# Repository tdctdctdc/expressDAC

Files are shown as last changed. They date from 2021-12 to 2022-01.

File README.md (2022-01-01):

# expressDAC

PCB ordered

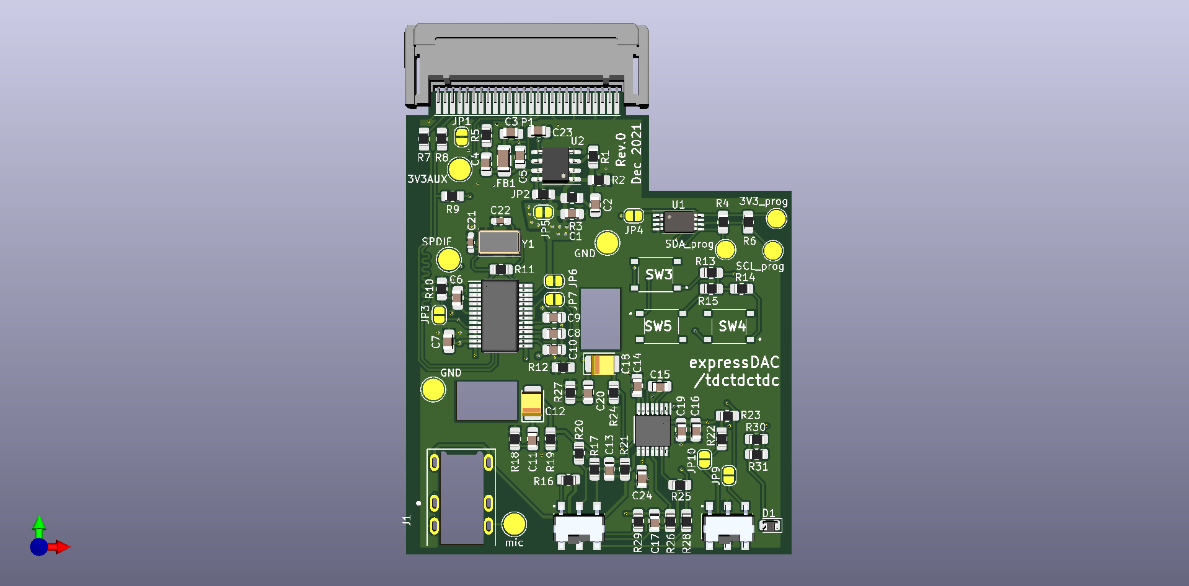
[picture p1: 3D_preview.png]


Proof of concept for a ExpressCard DAC

Using a TI part (PCM2704C) that does all the hard work (USB bridge + DAC) just to prove feasibility. It should be USB Audio class and need no driver whatsoever

Had to change the amplifier chip twice because of the shortage and it's pretty much the least interesting part. The LM4917 is very underwhelming compared to recent TI integrated, 3V3 headphone amplifier

The PCM2704C datasheet is very short (less than 50 pages for 4 variants of the chip !) and power supply rules are not clear. That's why there so many solder bridge. 

Also had to go with awkward footprints for the LDO and EEPROM because it's 2021 and everything is out of stock...

The main goal is to go noise free even with sensitive IEM.

Will be using salvaged expressCard connector since the only available commercial reference (100305702112lf) is on Arrow and I can't order it here.

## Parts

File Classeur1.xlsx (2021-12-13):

version | source | date | tool | number | name | tstamps | title | company | rev | date2 | source3 | number4 | value | ref | value5 | footprint | field | name6 | lib | part | description | names | tstamps7 | tstamp | datasheet | lib8 | part9 | description10 | docs | field11 | name12 | num | name13 | type | fp | alias | logical | uri | code | name14 | ref15 | pin
D |  |  |  |  |  |  |  |  |  |  |  |  |  |  | 0R | Resistor_SMD:R_0805_2012Metric_Pad1.20x1.40mm_HandSolder |  |  | Jumper | Jumper_2_Open | Jumper, 2-pole, open | / | / | 6129B10A | ~
D |  |  |  |  |  |  |  |  |  |  |  |  |  |  | 100k | Resistor_SMD:R_0805_2012Metric_Pad1.20x1.40mm_HandSolder |  |  | Device | R_Small_US | Resistor, small US symbol | / | / | 611EE0E7 | ~
D |  |  |  |  |  |  |  |  |  |  |  |  |  |  | 100k | Resistor_SMD:R_0805_2012Metric_Pad1.20x1.40mm_HandSolder |  |  | Device | R_Small_US | Resistor, small US symbol | / | / | 611E1D7C | ~
D |  |  |  |  |  |  |  |  |  |  |  |  |  |  | 100k | Resistor_SMD:R_0805_2012Metric_Pad1.20x1.40mm_HandSolder |  |  | Device | R_Small_US | Resistor, small US symbol | / | / | 616C3DC7 | ~
D |  |  |  |  |  |  |  |  |  |  |  |  |  |  | 100k | Resistor_SMD:R_0805_2012Metric_Pad1.20x1.40mm_HandSolder |  |  | Device | R_Small_US | Resistor, small US symbol | / | / | 616C469F | ~
D |  |  |  |  |  |  |  |  |  |  |  |  |  |  | 100k | Resistor_SMD:R_0805_2012Metric_Pad1.20x1.40mm_HandSolder |  |  | Device | R_Small_US | Resistor, small US symbol | / | / | 616C4A0D | ~
D |  |  |  |  |  |  |  |  |  |  |  |  |  |  | 100k | Resistor_SMD:R_0805_2012Metric_Pad1.20x1.40mm_HandSolder |  |  | Device | R_Small_US | Resistor, small US symbol | / | / | 618584DD | ~
D |  |  |  |  |  |  |  |  |  |  |  |  |  |  | 100k | Resistor_SMD:R_0805_2012Metric_Pad1.20x1.40mm_HandSolder |  |  | Device | R_Small_US | Resistor, small US symbol | / | / | 6189CDAD | ~
D |  |  |  |  |  |  |  |  |  |  |  |  |  |  | 100n | Capacitor_SMD:C_0805_2012Metric_Pad1.18x1.45mm_HandSolder |  |  | Device | C_Small | Unpolarized capacitor, small symbol | / | / | 6171208B | ~
D |  |  |  |  |  |  |  |  |  |  |  |  |  |  | 10k | Resistor_SMD:R_0805_2012Metric_Pad1.20x1.40mm_HandSolder |  |  | Device | R_US | Resistor, US symbol | / | / | 6115C9DD | ~
D |  |  |  |  |  |  |  |  |  |  |  |  |  |  |  | Capacitor_SMD:C_0805_2012Metric_Pad1.18x1.45mm_HandSolder |  |  | Device | C_Small | Unpolarized capacitor, small symbol | / | / | 6115BD5B | ~
D |  |  |  |  |  |  |  |  |  |  |  |  |  |  | 10u | Capacitor_SMD:C_0805_2012Metric_Pad1.18x1.45mm_HandSolder |  |  | Device | CP1_Small | Polarized capacitor, small US symbol | / | / | 612387CB | ~
D |  |  |  |  |  |  |  |  |  |  |  |  |  |  | 10u | Capacitor_Tantalum_SMD:CP_EIA-3528-21_Kemet-B_Pad1.50x2.35mm_HandSolder |  |  | Device | CP1_Small | Polarized capacitor, small US symbol | / | / | 611991A7 | ~
D |  |  |  |  |  |  |  |  |  |  |  |  |  |  | 10u | Capacitor_Tantalum_SMD:CP_EIA-3528-21_Kemet-B_Pad1.50x2.35mm_HandSolder |  |  | Device | CP1_Small | Polarized capacitor, small US symbol | / | / | 611C0A92 | ~
D |  |  |  |  |  |  |  |  |  |  |  |  |  |  | 10u | Capacitor_SMD:C_0805_2012Metric_Pad1.18x1.45mm_HandSolder |  |  | Device | CP1_Small | Polarized capacitor, small US symbol | / | / | 6134C5CA | ~
D |  |  |  |  |  |  |  |  |  |  |  |  |  |  | 15k | Resistor_SMD:R_0805_2012Metric_Pad1.20x1.40mm_HandSolder |  |  | Device | R_Small_US | Resistor, small US symbol | / | / | 61111F8E | ~
D |  |  |  |  |  |  |  |  |  |  |  |  |  |  | 18p | Capacitor_SMD:C_0603_1608Metric_Pad1.08x0.95mm_HandSolder |  |  | Device | C_Small | Unpolarized capacitor, small symbol | / | / | 6112DD15 | ~
D |  |  |  |  |  |  |  |  |  |  |  |  |  |  | 18p | Capacitor_SMD:C_0603_1608Metric_Pad1.08x0.95mm_HandSolder |  |  | Device | C_Small | Unpolarized capacitor, small symbol | / | / | 6112F506 | ~
D |  |  |  |  |  |  |  |  |  |  |  |  |  |  | 1k | Resistor_SMD:R_0805_2012Metric_Pad1.20x1.40mm_HandSolder |  |  | Device | R_Small_US | Resistor, small US symbol | / | / | 61117E01 | ~
D |  |  |  |  |  |  |  |  |  |  |  |  |  |  | 1k5 | Resistor_SMD:R_0805_2012Metric_Pad1.20x1.40mm_HandSolder |  |  | Device | R_Small_US | Resistor, small US symbol | / | / | 614A52DF | ~
D |  |  |  |  |  |  |  |  |  |  |  |  |  |  | 1M | Resistor_SMD:R_0805_2012Metric_Pad1.20x1.40mm_HandSolder |  |  | Device | R_Small_US | Resistor, small US symbol | / | / | 6113FC88 | ~
D |  |  |  |  |  |  |  |  |  |  |  |  |  |  | 1u | Capacitor_SMD:C_0805_2012Metric_Pad1.18x1.45mm_HandSolder |  |  | Device | C_Small | Unpolarized capacitor, small symbol | / | / | 611163AA | ~
D |  |  |  |  |  |  |  |  |  |  |  |  |  |  | 1u | Capacitor_SMD:C_0805_2012Metric_Pad1.18x1.45mm_HandSolder |  |  | Device | C_Small | Unpolarized capacitor, small symbol | / | / | 6116895D | ~
D |  |  |  |  |  |  |  |  |  |  |  |  |  |  | 1u | Capacitor_SMD:C_0805_2012Metric_Pad1.18x1.45mm_HandSolder |  |  | Device | C_Small | Unpolarized capacitor, small symbol | / | / | 6122887B | ~
D |  |  |  |  |  |  |  |  |  |  |  |  |  |  | 1u | Capacitor_SMD:C_0805_2012Metric_Pad1.18x1.45mm_HandSolder |  |  | Device | C_Small | Unpolarized capacitor, small symbol | / | / | 612515A7 | ~
D |  |  |  |  |  |  |  |  |  |  |  |  |  |  | 1u | Capacitor_SMD:C_0805_2012Metric_Pad1.18x1.45mm_HandSolder |  |  | Device | C_Small | Unpolarized capacitor, small symbol | / | / | 6125CF4C | ~
D |  |  |  |  |  |  |  |  |  |  |  |  |  |  | 1u | Capacitor_SMD:C_0805_2012Metric_Pad1.18x1.45mm_HandSolder |  |  | Device | C_Small | Unpolarized capacitor, small symbol | / | / | 61308E7B | ~
D |  |  |  |  |  |  |  |  |  |  |  |  |  |  | 2.2u | Capacitor_SMD:C_0805_2012Metric_Pad1.18x1.45mm_HandSolder |  |  | Device | C | Unpolarized capacitor | / | / | 611C6C12 | ~
D |  |  |  |  |  |  |  |  |  |  |  |  |  |  | 2.2u | Capacitor_SMD:C_0805_2012Metric_Pad1.18x1.45mm_HandSolder |  |  | Device | C | Unpolarized capacitor | / | / | 611D97B4 | ~
D |  |  |  |  |  |  |  |  |  |  |  |  |  |  | 20k | Resistor_SMD:R_0805_2012Metric_Pad1.20x1.40mm_HandSolder |  |  | Device | R_US | Resistor, US symbol | / | / | 61168B82 | ~
D |  |  |  |  |  |  |  |  |  |  |  |  |  |  | 20k | Resistor_SMD:R_0805_2012Metric_Pad1.20x1.40mm_HandSolder |  |  | Device | R_US | Resistor, US symbol | / | / | 615FAEEE | ~
D |  |  |  |  |  |  |  |  |  |  |  |  |  |  | 20k | Resistor_SMD:R_0805_2012Metric_Pad1.20x1.40mm_HandSolder |  |  | Device | R_US | Resistor, US symbol | / | / | 615FCD86 | ~
D |  |  |  |  |  |  |  |  |  |  |  |  |  |  | 220p | Capacitor_SMD:C_0805_2012Metric_Pad1.18x1.45mm_HandSolder |  |  | Device | C_Small | Unpolarized capacitor, small symbol | / | / | 611A2D30 | ~
D |  |  |  |  |  |  |  |  |  |  |  |  |  |  | 220p | Capacitor_SMD:C_0805_2012Metric_Pad1.18x1.45mm_HandSolder |  |  | Device | C_Small | Unpolarized capacitor, small symbol | / | / | 611C0A9C | ~
D |  |  |  |  |  |  |  |  |  |  |  |  |  |  | 22n | Capacitor_SMD:C_0805_2012Metric_Pad1.18x1.45mm_HandSolder |  |  | Device | C_Small | Unpolarized capacitor, small symbol | / | / | 613EB038 | ~
D |  |  |  |  |  |  |  |  |  |  |  |  |  |  | 22n | Capacitor_SMD:C_0805_2012Metric_Pad1.18x1.45mm_HandSolder |  |  | Device | C_Small | Unpolarized capacitor, small symbol | / | / | 613EBD72 | ~
D |  |  |  |  |  |  |  |  |  |  |  |  |  |  | 22R | Resistor_SMD:R_0805_2012Metric_Pad1.20x1.40mm_HandSolder |  |  | Device | R_Small_US | Resistor, small US symbol | / | / | 611486B3 | ~
D |  |  |  |  |  |  |  |  |  |  |  |  |  |  | 22R | Resistor_SMD:R_0805_2012Metric_Pad1.20x1.40mm_HandSolder |  |  | Device | R_Small_US | Resistor, small US symbol | / | / | 6114744C | ~
D |  |  |  |  |  |  |  |  |  |  |  |  |  |  | 22R | Resistor_SMD:R_0805_2012Metric_Pad1.20x1.40mm_HandSolder |  |  | Device | R_Small_US | Resistor, small US symbol | / | / | 613E8B5E | ~
D |  |  |  |  |  |  |  |  |  |  |  |  |  |  | 22R | Resistor_SMD:R_0805_2012Metric_Pad1.20x1.40mm_HandSolder |  |  | Device | R_Small_US | Resistor, small US symbol | / | / | 613E9E04 | ~
D |  |  |  |  |  |  |  |  |  |  |  |  |  |  | 24,3k | Resistor_SMD:R_0805_2012Metric_Pad1.20x1.40mm_HandSolder |  |  | Device | R_Small_US | Resistor, small US symbol | / | / | 6110FCD0 | ~
D |  |  |  |  |  |  |  |  |  |  |  |  |  |  | 24CW320T-I_OT | SamacSys_Parts:SOT95P280X145-5N | EEPROM 32 Kbit I2C Serial EEPROM with Software Write Protection, Industrial Temp | Description | 000_expresscard | 24CW320T-I_OT | EEPROM 32 Kbit I2C Serial EEPROM with Software Write Protection, Industrial Temp | / | / | 61501347 | https://componentsearchengine.com/Datasheets/1/24CW320T-I_OT.pdf
D |  |  |  |  |  |  |  |  |  |  |  |  |  |  | 24CW320T-I_OT | SamacSys_Parts:SOT95P280X145-5N | 1.45 | Height | 000_expresscard | 24CW320T-I_OT | EEPROM 32 Kbit I2C Serial EEPROM with Software Write Protection, Industrial Temp | / | / | 61501347 | https://componentsearchengine.com/Datasheets/1/24CW320T-I_OT.pdf
D |  |  |  |  |  |  |  |  |  |  |  |  |  |  | 24CW320T-I_OT | SamacSys_Parts:SOT95P280X145-5N | Microchip | Manufacturer_Name | 000_expresscard | 24CW320T-I_OT | EEPROM 32 Kbit I2C Serial EEPROM with Software Write Protection, Industrial Temp | / | / | 61501347 | https://componentsearchengine.com/Datasheets/1/24CW320T-I_OT.pdf
D |  |  |  |  |  |  |  |  |  |  |  |  |  |  | 24CW320T-I_OT | SamacSys_Parts:SOT95P280X145-5N | 24CW320T-I/OT | Manufacturer_Part_Number | 000_expresscard | 24CW320T-I_OT | EEPROM 32 Kbit I2C Serial EEPROM with Software Write Protection, Industrial Temp | / | / | 61501347 | https://componentsearchengine.com/Datasheets/1/24CW320T-I_OT.pdf
D |  |  |  |  |  |  |  |  |  |  |  |  |  |  | 24CW320T-I_OT | SamacSys_Parts:SOT95P280X145-5N | 579-24CW320T-I/OT | Mouser Part Number | 000_expresscard | 24CW320T-I_OT | EEPROM 32 Kbit I2C Serial EEPROM with Software Write Protection, Industrial Temp | / | / | 61501347 | https://componentsearchengine.com/Datasheets/1/24CW320T-I_OT.pdf
D |  |  |  |  |  |  |  |  |  |  |  |  |  |  | 24CW320T-I_OT | SamacSys_Parts:SOT95P280X145-5N | https://www.mouser.com/Search/Refine.aspx?Keyword=579-24CW320T-I%2FOT | Mouser Price/Stock | 000_expresscard | 24CW320T-I_OT | EEPROM 32 Kbit I2C Serial EEPROM with Software Write Protection, Industrial Temp | / | / | 61501347 | https://componentsearchengine.com/Datasheets/1/24CW320T-I_OT.pdf
D |  |  |  |  |  |  |  |  |  |  |  |  | R5 |  | 2R | Resistor_SMD:R_0805_2012Metric_Pad1.20x1.40mm_HandSolder |  |  | Device | R_Small_US | Resistor, small US symbol | / | / | 61309F95 | ~
D |  |  |  |  |  |  |  |  |  |  |  |  |  |  | 2u2 | Capacitor_SMD:C_0805_2012Metric_Pad1.18x1.45mm_HandSolder |  |  | Device | C_Small | Unpolarized capacitor, small symbol | / | / | 6111C309 | ~
D |  |  |  |  |  |  |  |  |  |  |  |  |  |  | 3V3_prog | TestPoint:TestPoint_Pad_D2.5mm |  |  | Connector | TestPoint | test point | / | / | 615730A0 | ~
D |  |  |  |  |  |  |  |  |  |  |  |  |  |  | 4.7u | Capacitor_SMD:C_0805_2012Metric_Pad1.18x1.45mm_HandSolder |  |  | Device | C | Unpolarized capacitor | / | / | 611EE218 | ~
D |  |  |  |  |  |  |  |  |  |  |  |  |  |  | 6k8 | Resistor_SMD:R_0805_2012Metric_Pad1.20x1.40mm_HandSolder |  |  | Device | R_US | Resistor, US symbol | / | / | 61236CEA | ~
D |  |  |  |  |  |  |  |  |  |  |  |  |  |  | 6k8 | Resistor_SMD:R_0805_2012Metric_Pad1.20x1.40mm_HandSolder |  |  | Device | R_US | Resistor, US symbol | / | / | 61293D7E | ~
D |  |  |  |  |  |  |  |  |  |  |  |  |  |  | ABM3C-12.000MHZ-D4Y-T | Crystal:Crystal_SMD_Abracon_ABM3C-4Pin_5.0x3.2mm |  |  | Device | Crystal | Two pin crystal | / | / | 61130E8C | ~
D |  |  |  |  |  |  |  |  |  |  |  |  |  |  | ADP7142AUJZ | Package_TO_SOT_SMD:TSOT-23-5 |  |  | Regulator_Linear | ADP7142AUJZ | 200mA, Low Noise, CMOS Low Dropout Regulator, Positive, Adjustable, TSOT-23-5 | / | / | 61105CFB | https://www.analog.com/media/en/technical-documentation/data-sheets/ADP7142.pdf
D |  |  |  |  |  |  |  |  |  |  |  |  |  |  | Express_Card | MYLIB:100305702112LF |  |  | 000_expresscard | Express_Card |  | / | / | 60F8C266
D |  |  |  |  |  |  |  |  |  |  |  |  |  |  | Ferrite_Bead_Small | Capacitor_SMD:C_1206_3216Metric_Pad1.33x1.80mm_HandSolder |  |  | Device | Ferrite_Bead_Small | Ferrite bead, small symbol | / | / | 611598B0 | ~
D |  |  |  |  |  |  |  |  |  |  |  |  |  |  | LM4917 | SamacSys_Parts:SOP65P640X120-14N | LM4917 Ground-Referenced, 95mW Stereo Headphone Amplifier | Description | 000_expresscard | LM4917 | LM4917 Ground-Referenced, 95mW Stereo Headphone Amplifier | / | / | 61834444 | http://www.ti.com/lit/gpn/lm4917
D |  |  |  |  |  |  |  |  |  |  |  |  |  |  | LM4917 | SamacSys_Parts:SOP65P640X120-14N | 1.2 | Height | 000_expresscard | LM4917 | LM4917 Ground-Referenced, 95mW Stereo Headphone Amplifier | / | / | 61834444 | http://www.ti.com/lit/gpn/lm4917
D |  |  |  |  |  |  |  |  |  |  |  |  |  |  | LM4917 | SamacSys_Parts:SOP65P640X120-14N | Texas Instruments | Manufacturer_Name | 000_expresscard | LM4917 | LM4917 Ground-Referenced, 95mW Stereo Headphone Amplifier | / | / | 61834444 | http://www.ti.com/lit/gpn/lm4917
D |  |  |  |  |  |  |  |  |  |  |  |  |  |  | LM4917 | SamacSys_Parts:SOP65P640X120-14N | LM4917MTX/NOPB | Manufacturer_Part_Number | 000_expresscard | LM4917 | LM4917 Ground-Referenced, 95mW Stereo Headphone Amplifier | / | / | 61834444 | http://www.ti.com/lit/gpn/lm4917
D |  |  |  |  |  |  |  |  |  |  |  |  |  |  | LM4917 | SamacSys_Parts:SOP65P640X120-14N | 926-LM4917MTX/NOPB | Mouser Part Number | 000_expresscard | LM4917 | LM4917 Ground-Referenced, 95mW Stereo Headphone Amplifier | / | / | 61834444 | http://www.ti.com/lit/gpn/lm4917
D |  |  |  |  |  |  |  |  |  |  |  |  |  |  | LM4917 | SamacSys_Parts:SOP65P640X120-14N | https://www.mouser.co.uk/ProductDetail/Texas-Instruments/LM4917MTX-NOPB?qs=QbsRYf82W3E34pt9CCcZSQ%3D%3D | Mouser Price/Stock | 000_expresscard | LM4917 | LM4917 Ground-Referenced, 95mW Stereo Headphone Amplifier | / | / | 61834444 | http://www.ti.com/lit/gpn/lm4917
D |  |  |  |  |  |  |  |  |  |  |  |  |  |  | mic | TestPoint:TestPoint_Pad_D3.0mm |  |  | Connector | TestPoint | test point | / | / | 6199E316 | ~
D |  |  |  |  |  |  |  |  |  |  |  |  |  | R17 | N/C | Resistor_SMD:R_0805_2012Metric_Pad1.20x1.40mm_HandSolder |  |  | Device | R_US | Resistor, US symbol | / | / | 612348EE | ~
D |  |  |  |  |  |  |  |  |  |  |  |  |  | R28 | N/C | Resistor_SMD:R_0805_2012Metric_Pad1.20x1.40mm_HandSolder |  |  | Device | R_US | Resistor, US symbol | / | / | 61293D78 | ~
D |  |  |  |  |  |  |  |  |  |  |  |  |  | R19 | N/C | Resistor_SMD:R_0805_2012Metric_Pad1.20x1.40mm_HandSolder |  |  | Device | R_Small_US | Resistor, small US symbol | / | / | 614B4043 | ~
D |  |  |  |  |  |  |  |  |  |  |  |  |  | R24 | N/C | Resistor_SMD:R_0805_2012Metric_Pad1.20x1.40mm_HandSolder |  |  | Device | R_Small_US | Resistor, small US symbol | / | / | 614B51AE | ~
D |  |  |  |  |  |  |  |  |  |  |  |  |  |  | PCM2704CDBR | SamacSys_Parts:SOP65P780X200-28N | 98dB SNR Stereo Full Speed DAC with line-out & S/PDIF output, Bus/Self-powered (Ext. ROM Interface) | Description | 000_expresscard | PCM2704CDBR | 98dB SNR Stereo Full Speed DAC with line-out & S/PDIF output, Bus/Self-powered (Ext. ROM Interface) | / | / | 616F0F6C | http://www.ti.com/lit/gpn/pcm2704c
D |  |  |  |  |  |  |  |  |  |  |  |  |  |  | PCM2704CDBR | SamacSys_Parts:SOP65P780X200-28N | 2 | Height | 000_expresscard | PCM2704CDBR | 98dB SNR Stereo Full Speed DAC with line-out & S/PDIF output, Bus/Self-powered (Ext. ROM Interface) | / | / | 616F0F6C | http://www.ti.com/lit/gpn/pcm2704c
D |  |  |  |  |  |  |  |  |  |  |  |  |  |  | PCM2704CDBR | SamacSys_Parts:SOP65P780X200-28N | Texas Instruments | Manufacturer_Name | 000_expresscard | PCM2704CDBR | 98dB SNR Stereo Full Speed DAC with line-out & S/PDIF output, Bus/Self-powered (Ext. ROM Interface) | / | / | 616F0F6C | http://www.ti.com/lit/gpn/pcm2704c
D |  |  |  |  |  |  |  |  |  |  |  |  |  |  | PCM2704CDBR | SamacSys_Parts:SOP65P780X200-28N | PCM2704CDBR | Manufacturer_Part_Number | 000_expresscard | PCM2704CDBR | 98dB SNR Stereo Full Speed DAC with line-out & S/PDIF output, Bus/Self-powered (Ext. ROM Interface) | / | / | 616F0F6C | http://www.ti.com/lit/gpn/pcm2704c
D |  |  |  |  |  |  |  |  |  |  |  |  |  |  | PCM2704CDBR | SamacSys_Parts:SOP65P780X200-28N | 595-PCM2704CDBR | Mouser Part Number | 000_expresscard | PCM2704CDBR | 98dB SNR Stereo Full Speed DAC with line-out & S/PDIF output, Bus/Self-powered (Ext. ROM Interface) | / | / | 616F0F6C | http://www.ti.com/lit/gpn/pcm2704c
D |  |  |  |  |  |  |  |  |  |  |  |  |  |  | PCM2704CDBR | SamacSys_Parts:SOP65P780X200-28N | https://www.mouser.co.uk/ProductDetail/Texas-Instruments/PCM2704CDBR/?qs=luhu8ESwuKyEcaL1a6bxNA%3D%3D | Mouser Price/Stock | 000_expresscard | PCM2704CDBR | 98dB SNR Stereo Full Speed DAC with line-out & S/PDIF output, Bus/Self-powered (Ext. ROM Interface) | / | / | 616F0F6C | http://www.ti.com/lit/gpn/pcm2704c
D |  |  |  |  |  |  |  |  |  |  |  |  |  |  | R_US | Resistor_SMD:R_0805_2012Metric_Pad1.20x1.40mm_HandSolder |  |  | Device | R_US | Resistor, US symbol | / | / | 611C0A70 | ~
D |  |  |  |  |  |  |  |  |  |  |  |  |  |  | R_US | Resistor_SMD:R_0805_2012Metric_Pad1.20x1.40mm_HandSolder |  |  | Device | R_US | Resistor, US symbol | / | / | 611C0A76 | ~
D |  |  |  |  |  |  |  |  |  |  |  |  |  |  | SCL_prog | TestPoint:TestPoint_Pad_D2.5mm |  |  | Connector | TestPoint | test point | / | / | 61643A62 | ~
D |  |  |  |  |  |  |  |  |  |  |  |  |  |  | SDA_prog | TestPoint:TestPoint_Pad_D2.5mm |  |  | Connector | TestPoint | test point | / | / | 61642B50 | ~
D |  |  |  |  |  |  |  |  |  |  |  |  |  |  | SJ2-35355A-SMT-TR | MYLIB:CUI_SJ2-35355A-SMT-TR | CUI | MF | 000_expresscard | SJ2-35355A-SMT-TR |  | / | / | 610A3ED8
D |  |  |  |  |  |  |  |  |  |  |  |  |  |  | SJ2-35355A-SMT-TR | MYLIB:CUI_SJ2-35355A-SMT-TR | SJ2-35355A-SMT-TR | MPN | 000_expresscard | SJ2-35355A-SMT-TR |  | / | / | 610A3ED8
D |  |  |  |  |  |  |  |  |  |  |  |  |  |  | SJ2-35355A-SMT-TR | MYLIB:CUI_SJ2-35355A-SMT-TR | Manufacturer recommendation | STANDARD | 000_expresscard | SJ2-35355A-SMT-TR |  | / | / | 610A3ED8
D |  |  |  |  |  |  |  |  |  |  |  |  |  |  | SolderJumper_2_Bridged | Jumper:SolderJumper-2_P1.3mm_Bridged_RoundedPad1.0x1.5mm |  |  | Jumper | SolderJumper_2_Bridged | Solder Jumper, 2-pole, closed/bridged | / | / | 6120BC43 | ~
D |  |  |  |  |  |  |  |  |  |  |  |  |  |  | SolderJumper_2_Bridged | Jumper:SolderJumper-2_P1.3mm_Bridged_RoundedPad1.0x1.5mm |  |  | Jumper | SolderJumper_2_Bridged | Solder Jumper, 2-pole, closed/bridged | / | / | 612B8AB4 | ~
D |  |  |  |  |  |  |  |  |  |  |  |  |  |  | SolderJumper_2_Bridged | Jumper:SolderJumper-2_P1.3mm_Bridged_RoundedPad1.0x1.5mm |  |  | Jumper | SolderJumper_2_Bridged | Solder Jumper, 2-pole, closed/bridged | / | / | 61377CE6 | ~
D |  |  |  |  |  |  |  |  |  |  |  |  |  |  | SolderJumper_2_Open | Jumper:SolderJumper-2_P1.3mm_Open_RoundedPad1.0x1.5mm |  |  | Jumper | SolderJumper_2_Open | Solder Jumper, 2-pole, open | / | / | 611ECFCB | ~
D |  |  |  |  |  |  |  |  |  |  |  |  |  |  | SolderJumper_2_Open | Jumper:SolderJumper-2_P1.3mm_Open_RoundedPad1.0x1.5mm |  |  | Jumper | SolderJumper_2_Open | Solder Jumper, 2-pole, open | / | / | 6128F622 | ~
D |  |  |  |  |  |  |  |  |  |  |  |  |  |  | SolderJumper_2_Open | Jumper:SolderJumper-2_P1.3mm_Open_RoundedPad1.0x1.5mm |  |  | Jumper | SolderJumper_2_Open | Solder Jumper, 2-pole, open | / | / | 61410325 | ~
D |  |  |  |  |  |  |  |  |  |  |  |  |  |  | SolderJumper_2_Open | Jumper:SolderJumper-2_P1.3mm_Open_RoundedPad1.0x1.5mm |  |  | Jumper | SolderJumper_2_Open | Solder Jumper, 2-pole, open | / | / | 61412C7E | ~
D |  |  |  |  |  |  |  |  |  |  |  |  |  |  | SolderJumper_2_Open | Jumper:SolderJumper-2_P1.3mm_Open_RoundedPad1.0x1.5mm |  |  | Jumper | SolderJumper_2_Open | Solder Jumper, 2-pole, open | / | / | 6154326C | ~
D |  |  |  |  |  |  |  |  |  |  |  |  |  |  | SolderJumper_2_Open | Jumper:SolderJumper-2_P1.3mm_Open_RoundedPad1.0x1.5mm |  |  | Jumper | SolderJumper_2_Open | Solder Jumper, 2-pole, open | / | / | 61857940 | ~
D |  |  |  |  |  |  |  |  |  |  |  |  |  |  | SolderJumper_2_Open | Jumper:SolderJumper-2_P1.3mm_Open_RoundedPad1.0x1.5mm |  |  | Jumper | SolderJumper_2_Open | Solder Jumper, 2-pole, open | / | / | 61857D33 | ~
D |  |  |  |  |  |  |  |  |  |  |  |  |  |  | SPDIF | TestPoint:TestPoint_Pad_D3.0mm |  |  | Connector | TestPoint | test point | / | / | 61A00691 | ~
D |  |  |  |  |  |  |  |  |  |  |  |  |  |  | SW_DPDT_x2 | SamacSys_Parts:PTS526SM08SMTR2LFS |  |  | Switch | SW_Push | Push button switch, generic, two pins | / | / | 61177A72 | ~
D |  |  |  |  |  |  |  |  |  |  |  |  |  |  | SW_DPDT_x2 | SamacSys_Parts:PTS526SM08SMTR2LFS |  |  | Switch | SW_Push | Push button switch, generic, two pins | / | / | 611C3B86 | ~
D |  |  |  |  |  |  |  |  |  |  |  |  |  |  | SW_DPDT_x2 | SamacSys_Parts:PTS526SM08SMTR2LFS |  |  | Switch | SW_Push | Push button switch, generic, two pins | / | / | 611C44CD | ~
D |  |  |  |  |  |  |  |  |  |  |  |  |  |  | SW_DPDT_x2 | SamacSys_Parts:AYZ0202AGRLC |  |  | Switch | SW_DPDT_x2 | Switch, dual pole double throw, separate symbols | / | / | 612225A5
D |  |  |  |  |  |  |  |  |  |  |  |  |  |  | SW_DPDT_x2 | SamacSys_Parts:AYZ0202AGRLC |  |  | Switch | SW_DPDT_x2 | Switch, dual pole double throw, separate symbols | / | / | 613BDD1F
D | C:\Users\Thomas\CAD\expressUSB\expressUSB\expressDAC.sch | 15/11/2021 23:08:59 | Eeschema (5.1.7)-1 | 1 | / | / |  |  |  |  | expressDAC.sch | 1
D | C:\Users\Thomas\CAD\expressUSB\expressUSB\expressDAC.sch | 15/11/2021 23:08:59 | Eeschema (5.1.7)-1 | 1 | / | / |  |  |  |  | expressDAC.sch | 2
D | C:\Users\Thomas\CAD\expressUSB\expressUSB\expressDAC.sch | 15/11/2021 23:08:59 | Eeschema (5.1.7)-1 | 1 | / | / |  |  |  |  | expressDAC.sch | 3
D | C:\Users\Thomas\CAD\expressUSB\expressUSB\expressDAC.sch | 15/11/2021 23:08:59 | Eeschema (5.1.7)-1 | 1 | / | / |  |  |  |  | expressDAC.sch | 4
D |  |  |  |  |  |  |  |  |  |  |  |  |  |  |  |  |  |  |  |  |  |  |  |  |  | 000_expresscard | 24CW320T-I_OT | EEPROM 32 Kbit I2C Serial EEPROM with Software Write Protection, Industrial Temp | https://componentsearchengine.com/Datasheets/1/24CW320T-I_OT.pdf | U | Reference
D |  |  |  |  |  |  |  |  |  |  |  |  |  |  |  |  |  |  |  |  |  |  |  |  |  | 000_expresscard | 24CW320T-I_OT | EEPROM 32 Kbit I2C Serial EEPROM with Software Write Protection, Industrial Temp | https://componentsearchengine.com/Datasheets/1/24CW320T-I_OT.pdf | 24CW320T-I_OT | Value
D |  |  |  |  |  |  |  |  |  |  |  |  |  |  |  |  |  |  |  |  |  |  |  |  |  | 000_expresscard | 24CW320T-I_OT | EEPROM 32 Kbit I2C Serial EEPROM with Software Write Protection, Industrial Temp | https://componentsearchengine.com/Datasheets/1/24CW320T-I_OT.pdf | SOT95P280X145-5N | Footprint
D |  |  |  |  |  |  |  |  |  |  |  |  |  |  |  |  |  |  |  |  |  |  |  |  |  | 000_expresscard | 24CW320T-I_OT | EEPROM 32 Kbit I2C Serial EEPROM with Software Write Protection, Industrial Temp | https://componentsearchengine.com/Datasheets/1/24CW320T-I_OT.pdf | https://componentsearchengine.com/Datasheets/1/24CW320T-I_OT.pdf | Datasheet
D |  |  |  |  |  |  |  |  |  |  |  |  |  |  |  |  |  |  |  |  |  |  |  |  |  | 000_expresscard | 24CW320T-I_OT | EEPROM 32 Kbit I2C Serial EEPROM with Software Write Protection, Industrial Temp | https://componentsearchengine.com/Datasheets/1/24CW320T-I_OT.pdf | EEPROM 32 Kbit I2C Serial EEPROM with Software Write Protection, Industrial Temp | Description
D |  |  |  |  |  |  |  |  |  |  |  |  |  |  |  |  |  |  |  |  |  |  |  |  |  | 000_expresscard | 24CW320T-I_OT | EEPROM 32 Kbit I2C Serial EEPROM with Software Write Protection, Industrial Temp | https://componentsearchengine.com/Datasheets/1/24CW320T-I_OT.pdf | 1.45 | Height
D |  |  |  |  |  |  |  |  |  |  |  |  |  |  |  |  |  |  |  |  |  |  |  |  |  | 000_expresscard | 24CW320T-I_OT | EEPROM 32 Kbit I2C Serial EEPROM with Software Write Protection, Industrial Temp | https://componentsearchengine.com/Datasheets/1/24CW320T-I_OT.pdf | 579-24CW320T-I/OT | Mouser Part Number
D |  |  |  |  |  |  |  |  |  |  |  |  |  |  |  |  |  |  |  |  |  |  |  |  |  | 000_expresscard | 24CW320T-I_OT | EEPROM 32 Kbit I2C Serial EEPROM with Software Write Protection, Industrial Temp | https://componentsearchengine.com/Datasheets/1/24CW320T-I_OT.pdf | https://www.mouser.com/Search/Refine.aspx?Keyword=579-24CW320T-I%2FOT | Mouser Price/Stock
D |  |  |  |  |  |  |  |  |  |  |  |  |  |  |  |  |  |  |  |  |  |  |  |  |  | 000_expresscard | 24CW320T-I_OT | EEPROM 32 Kbit I2C Serial EEPROM with Software Write Protection, Industrial Temp | https://componentsearchengine.com/Datasheets/1/24CW320T-I_OT.pdf | Microchip | Manufacturer_Name
D |  |  |  |  |  |  |  |  |  |  |  |  |  |  |  |  |  |  |  |  |  |  |  |  |  | 000_expresscard | 24CW320T-I_OT | EEPROM 32 Kbit I2C Serial EEPROM with Software Write Protection, Industrial Temp | https://componentsearchengine.com/Datasheets/1/24CW320T-I_OT.pdf | 24CW320T-I/OT | Manufacturer_Part_Number
D |  |  |  |  |  |  |  |  |  |  |  |  |  |  |  |  |  |  |  |  |  |  |  |  |  | 000_expresscard | 24CW320T-I_OT | EEPROM 32 Kbit I2C Serial EEPROM with Software Write Protection, Industrial Temp | https://componentsearchengine.com/Datasheets/1/24CW320T-I_OT.pdf |  |  | 1 | SCL | passive
D |  |  |  |  |  |  |  |  |  |  |  |  |  |  |  |  |  |  |  |  |  |  |  |  |  | 000_expresscard | 24CW320T-I_OT | EEPROM 32 Kbit I2C Serial EEPROM with Software Write Protection, Industrial Temp | https://componentsearchengine.com/Datasheets/1/24CW320T-I_OT.pdf |  |  | 2 | VSS | passive
D |  |  |  |  |  |  |  |  |  |  |  |  |  |  |  |  |  |  |  |  |  |  |  |  |  | 000_expresscard | 24CW320T-I_OT | EEPROM 32 Kbit I2C Serial EEPROM with Software Write Protection, Industrial Temp | https://componentsearchengine.com/Datasheets/1/24CW320T-I_OT.pdf |  |  | 3 | SDA | passive
D |  |  |  |  |  |  |  |  |  |  |  |  |  |  |  |  |  |  |  |  |  |  |  |  |  | 000_expresscard | 24CW320T-I_OT | EEPROM 32 Kbit I2C Serial EEPROM with Software Write Protection, Industrial Temp | https://componentsearchengine.com/Datasheets/1/24CW320T-I_OT.pdf |  |  | 4 | VCC | passive
D |  |  |  |  |  |  |  |  |  |  |  |  |  |  |  |  |  |  |  |  |  |  |  |  |  | 000_expresscard | 24CW320T-I_OT | EEPROM 32 Kbit I2C Serial EEPROM with Software Write Protection, Industrial Temp | https://componentsearchengine.com/Datasheets/1/24CW320T-I_OT.pdf |  |  | 5 | NC | NotConnected
D |  |  |  |  |  |  |  |  |  |  |  |  |  |  |  |  |  |  |  |  |  |  |  |  |  | 000_expresscard | Express_Card |  |  | P | Reference
D |  |  |  |  |  |  |  |  |  |  |  |  |  |  |  |  |  |  |  |  |  |  |  |  |  | 000_expresscard | Express_Card |  |  | Express_Card | Value
D |  |  |  |  |  |  |  |  |  |  |  |  |  |  |  |  |  |  |  |  |  |  |  |  |  | 000_expresscard | Express_Card |  |  |  |  | 1 | GND | unspc
D |  |  |  |  |  |  |  |  |  |  |  |  |  |  |  |  |  |  |  |  |  |  |  |  |  | 000_expresscard | Express_Card |  |  |  |  | 2 | USB_D- | unspc
D |  |  |  |  |  |  |  |  |  |  |  |  |  |  |  |  |  |  |  |  |  |  |  |  |  | 000_expresscard | Express_Card |  |  |  |  | 3 | USB_D+ | unspc
D |  |  |  |  |  |  |  |  |  |  |  |  |  |  |  |  |  |  |  |  |  |  |  |  |  | 000_expresscard | Express_Card |  |  |  |  | 4 | CP_USB | unspc
D |  |  |  |  |  |  |  |  |  |  |  |  |  |  |  |  |  |  |  |  |  |  |  |  |  | 000_expresscard | Express_Card |  |  |  |  | 5 | RSVD0 | unspc
D |  |  |  |  |  |  |  |  |  |  |  |  |  |  |  |  |  |  |  |  |  |  |  |  |  | 000_expresscard | Express_Card |  |  |  |  | 6 | RSVD0 | unspc
D |  |  |  |  |  |  |  |  |  |  |  |  |  |  |  |  |  |  |  |  |  |  |  |  |  | 000_expresscard | Express_Card |  |  |  |  | 7 | SMB_CLK | unspc
D |  |  |  |  |  |  |  |  |  |  |  |  |  |  |  |  |  |  |  |  |  |  |  |  |  | 000_expresscard | Express_Card |  |  |  |  | 8 | SMB_DATA | unspc
D |  |  |  |  |  |  |  |  |  |  |  |  |  |  |  |  |  |  |  |  |  |  |  |  |  | 000_expresscard | Express_Card |  |  |  |  | 9 | 1.5V | unspc
D |  |  |  |  |  |  |  |  |  |  |  |  |  |  |  |  |  |  |  |  |  |  |  |  |  | 000_expresscard | Express_Card |  |  |  |  | 10 | 1.5V | unspc
D |  |  |  |  |  |  |  |  |  |  |  |  |  |  |  |  |  |  |  |  |  |  |  |  |  | 000_expresscard | Express_Card |  |  |  |  | 11 | WAKE# | unspc
D |  |  |  |  |  |  |  |  |  |  |  |  |  |  |  |  |  |  |  |  |  |  |  |  |  | 000_expresscard | Express_Card |  |  |  |  | 12 | +3.3VAUX# | unspc
D |  |  |  |  |  |  |  |  |  |  |  |  |  |  |  |  |  |  |  |  |  |  |  |  |  | 000_expresscard | Express_Card |  |  |  |  | 13 | PERST# | unspc
D |  |  |  |  |  |  |  |  |  |  |  |  |  |  |  |  |  |  |  |  |  |  |  |  |  | 000_expresscard | Express_Card |  |  |  |  | 14 | +3.3V | unspc
D |  |  |  |  |  |  |  |  |  |  |  |  |  |  |  |  |  |  |  |  |  |  |  |  |  | 000_expresscard | Express_Card |  |  |  |  | 15 | +3.3V | unspc
D |  |  |  |  |  |  |  |  |  |  |  |  |  |  |  |  |  |  |  |  |  |  |  |  |  | 000_expresscard | Express_Card |  |  |  |  | 16 | CLKREG# | unspc
D |  |  |  |  |  |  |  |  |  |  |  |  |  |  |  |  |  |  |  |  |  |  |  |  |  | 000_expresscard | Express_Card |  |  |  |  | 17 | GND | unspc
D |  |  |  |  |  |  |  |  |  |  |  |  |  |  |  |  |  |  |  |  |  |  |  |  |  | 000_expresscard | Express_Card |  |  |  |  | 18 | REFCLK- | unspc
D |  |  |  |  |  |  |  |  |  |  |  |  |  |  |  |  |  |  |  |  |  |  |  |  |  | 000_expresscard | Express_Card |  |  |  |  | 19 | REFCLK+ | unspc
D |  |  |  |  |  |  |  |  |  |  |  |  |  |  |  |  |  |  |  |  |  |  |  |  |  | 000_expresscard | Express_Card |  |  |  |  | 20 | GND | unspc
D |  |  |  |  |  |  |  |  |  |  |  |  |  |  |  |  |  |  |  |  |  |  |  |  |  | 000_expresscard | Express_Card |  |  |  |  | 21 | PER0- | unspc
D |  |  |  |  |  |  |  |  |  |  |  |  |  |  |  |  |  |  |  |  |  |  |  |  |  | 000_expresscard | Express_Card |  |  |  |  | 22 | PER0+ | unspc
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

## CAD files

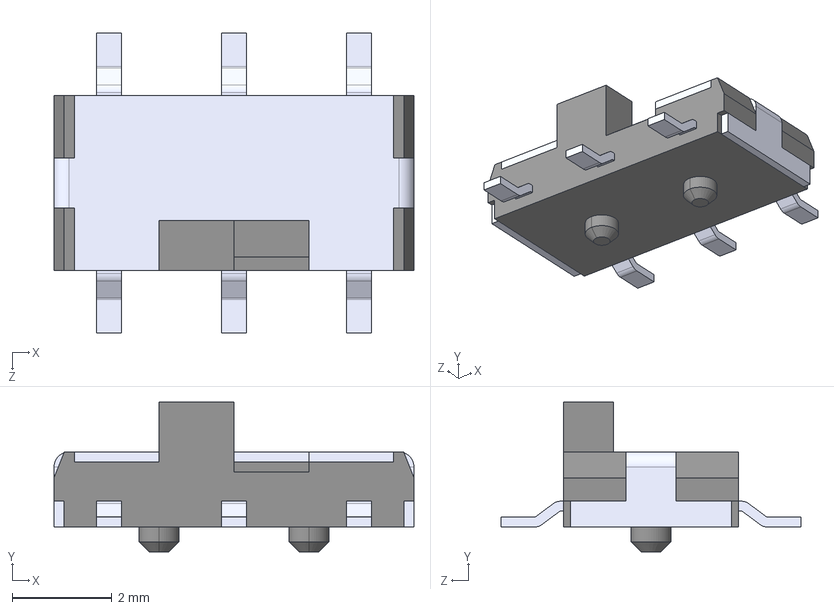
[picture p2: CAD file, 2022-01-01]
3D/AYZ0202AGRLC--3DModel-STEP-56544.STEP
7.20 x 3.00 x 6.00 mm

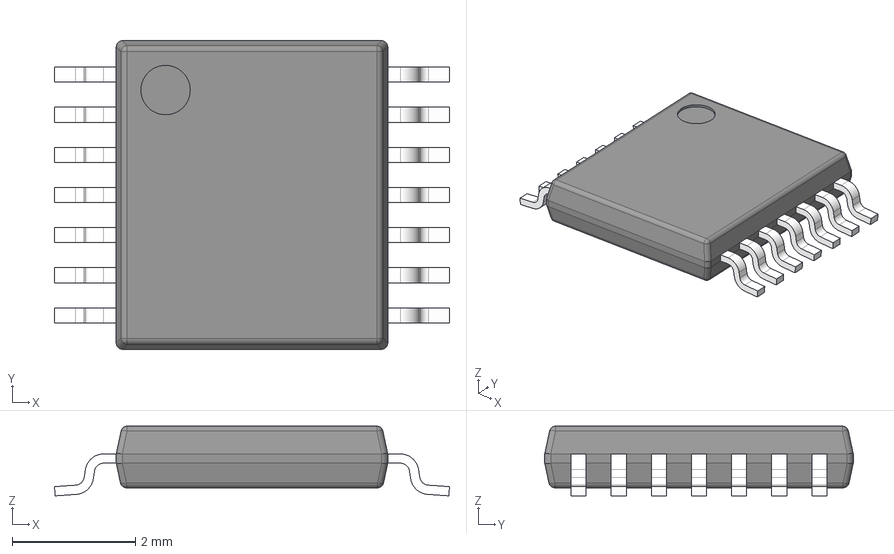
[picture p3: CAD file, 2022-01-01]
3D/LM4917MTX_NOPB.stp
6.40 x 5.00 x 1.13 mm
BODY-TSSOP
LEAD-TSSOP x 14
PIN1

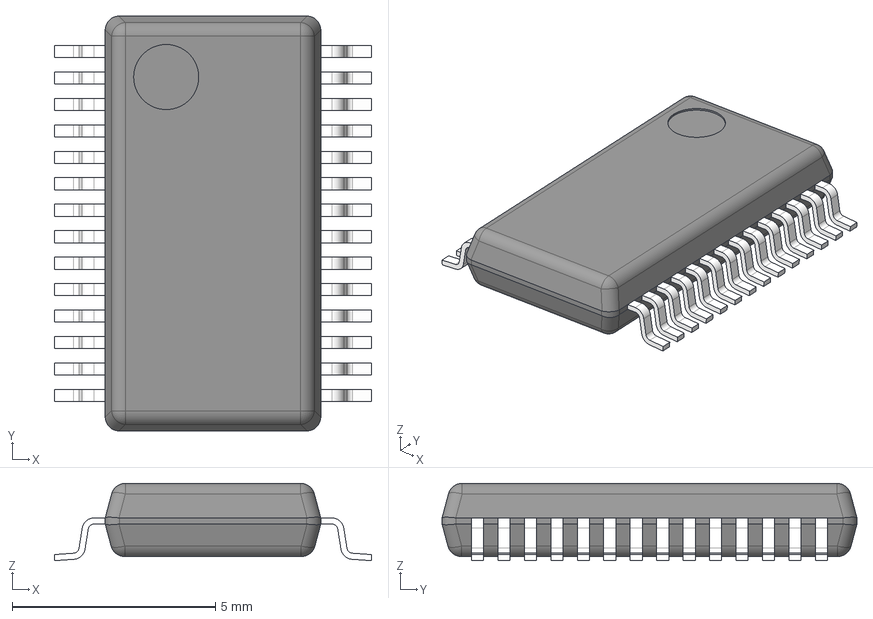
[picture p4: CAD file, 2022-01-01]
3D/PCM2704CDBR.stp
7.80 x 10.2 x 1.90 mm
BODY-SSOP
LEAD-SSOP x 28
PIN1

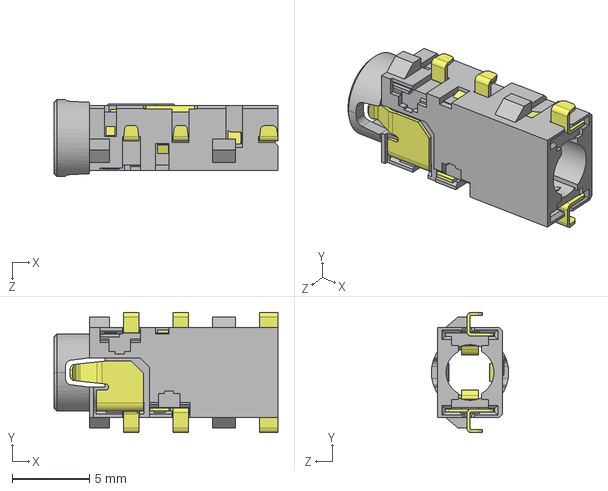
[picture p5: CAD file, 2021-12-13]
3D/CUI_DEVICES_SJ2-35355A-SMT-TR.step
14.5 x 7.80 x 5.00 mm

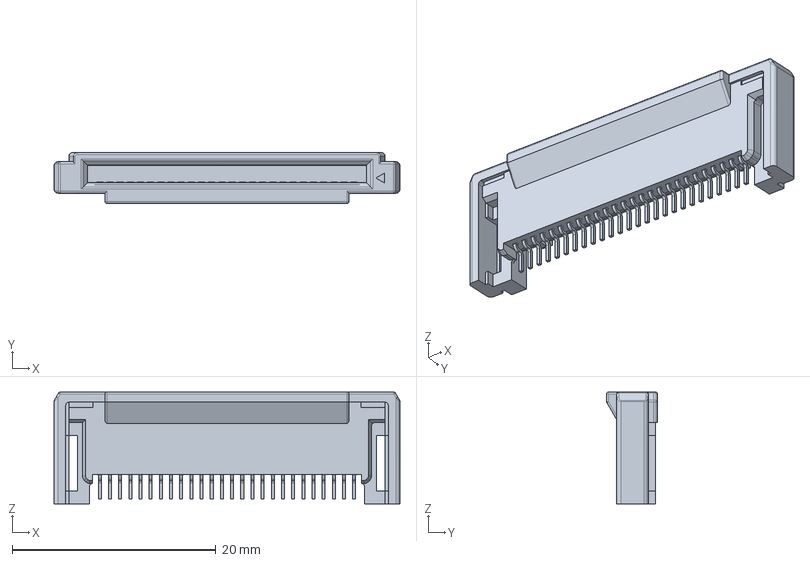
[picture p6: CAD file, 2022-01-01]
3D/100305702112lf.stp
34.0 x 5.00 x 11.0 mm

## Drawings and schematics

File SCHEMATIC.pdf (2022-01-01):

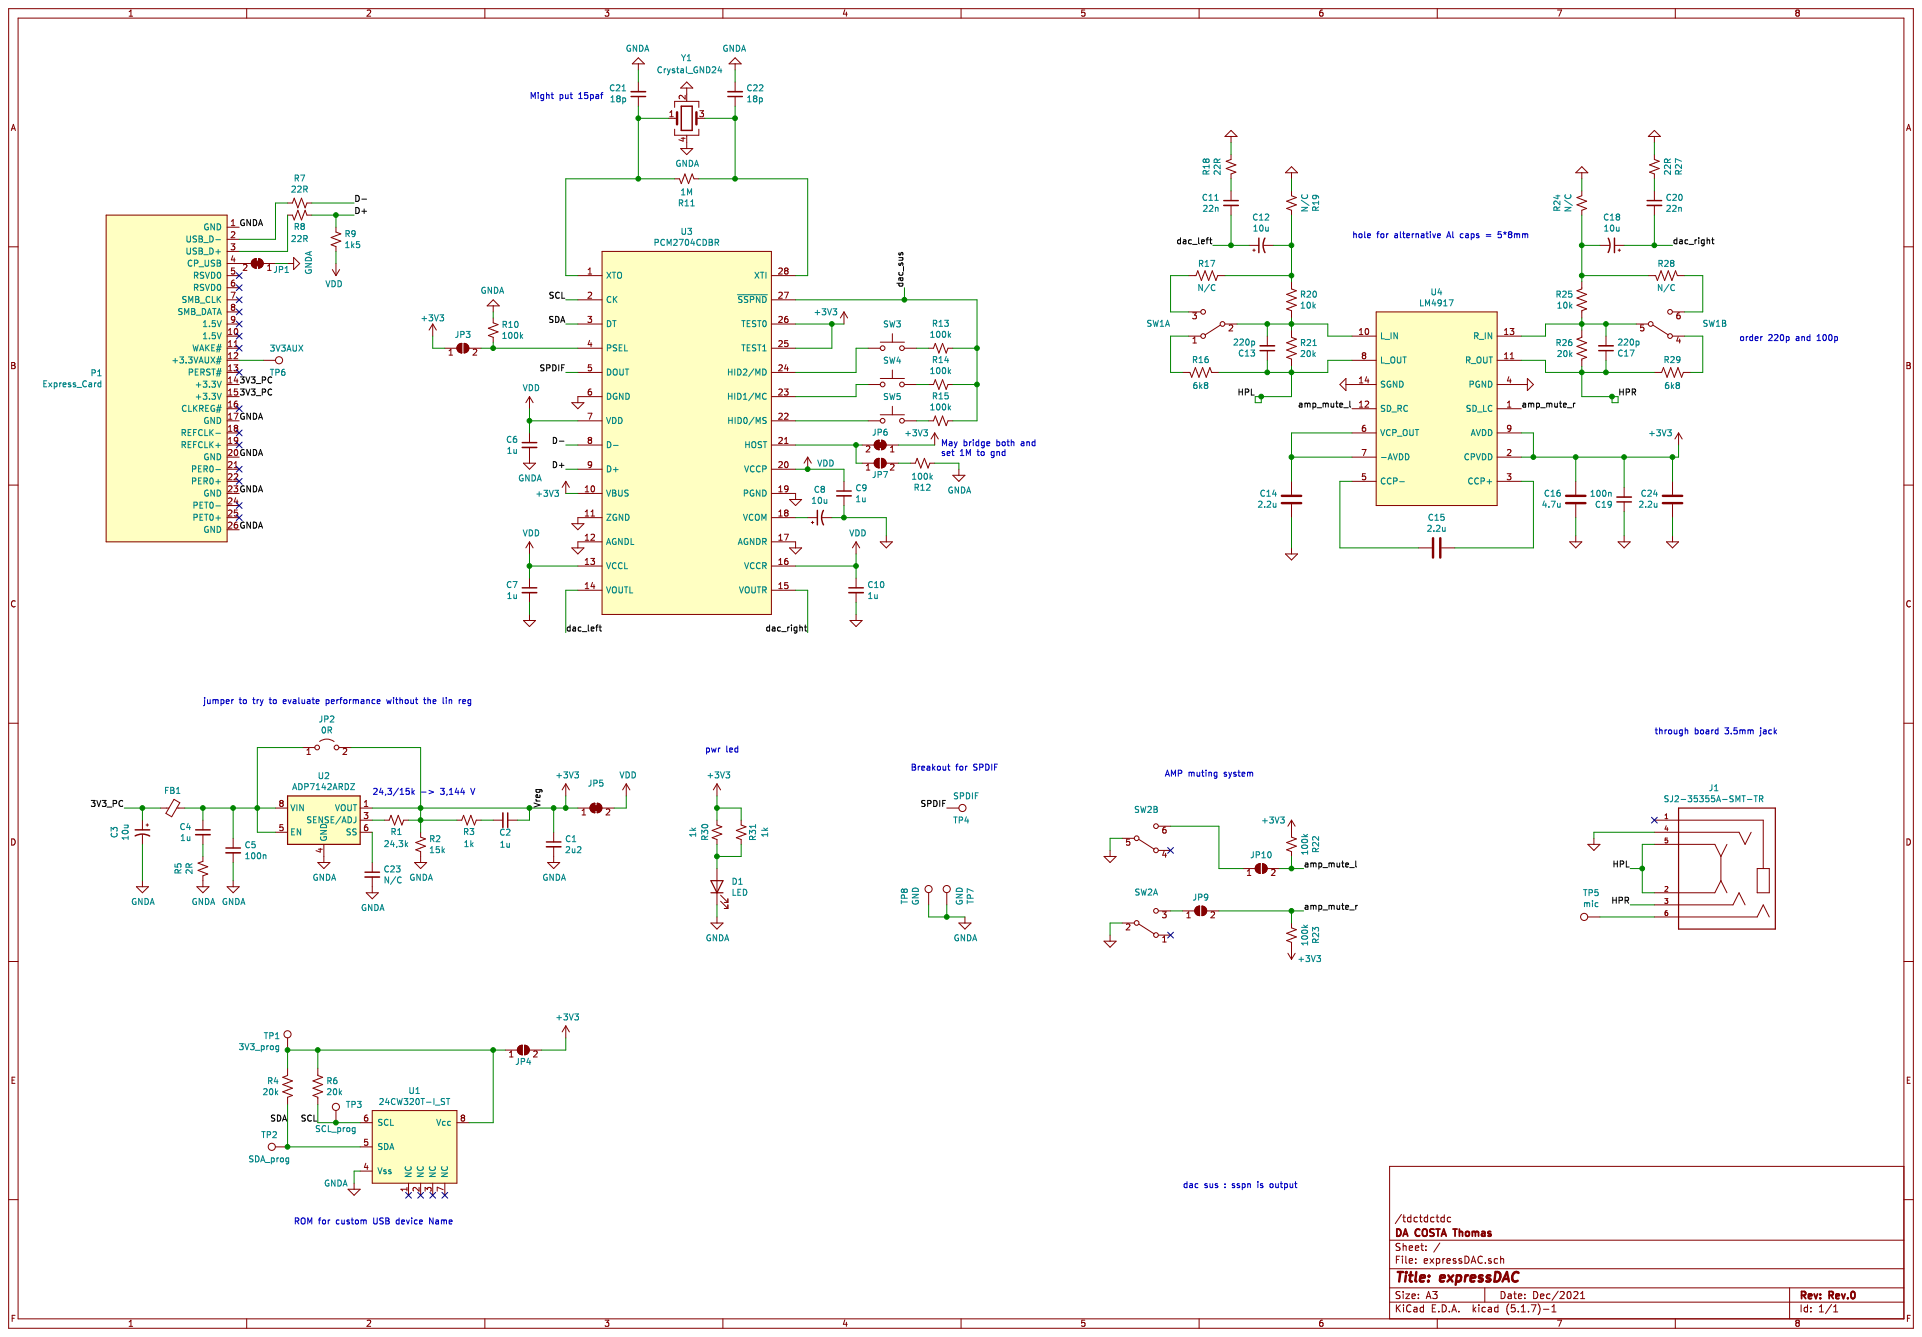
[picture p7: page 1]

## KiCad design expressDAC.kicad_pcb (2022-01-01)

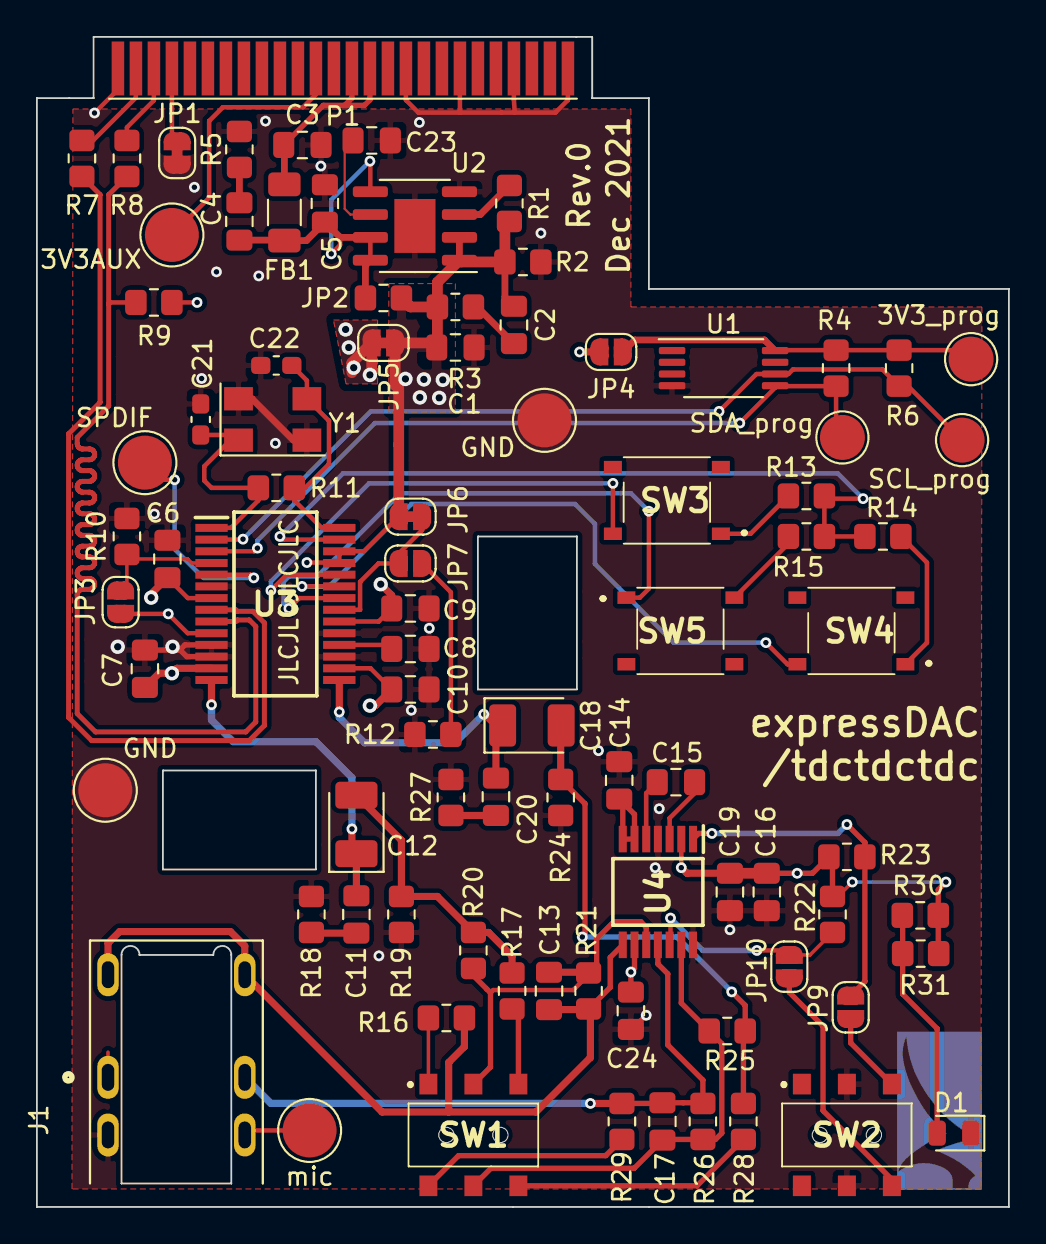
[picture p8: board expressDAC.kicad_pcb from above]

Board: 4 copper layers, 54.0 x 65.0 mm, 86 parts (0 on the bottom side), 55 nets.

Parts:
C1: 2u2; C_0805_2012Metric_Pad1.18x1.45mm_HandSolder
C2, C4, C6, C7, C9, C10: 1u; C_0805_2012Metric_Pad1.18x1.45mm_HandSolder
C3, C8: 10u; C_0805_2012Metric_Pad1.18x1.45mm_HandSolder
C5, C19: 100n; C_0805_2012Metric_Pad1.18x1.45mm_HandSolder
C11, C20: 22n; C_0805_2012Metric_Pad1.18x1.45mm_HandSolder
C12, C18: 10u; CP_EIA-3528-21_Kemet-B_Pad1.50x2.35mm_HandSolder
C13, C17: 220p; C_0805_2012Metric_Pad1.18x1.45mm_HandSolder
C14, C15, C24: 2.2u; C_0805_2012Metric_Pad1.18x1.45mm_HandSolder
C16: 4.7u; C_0805_2012Metric_Pad1.18x1.45mm_HandSolder
C21, C22: 18p; C_0603_1608Metric_Pad1.08x0.95mm_HandSolder
C23: N/C; C_0805_2012Metric_Pad1.18x1.45mm_HandSolder
D1: LED; D_0805_2012Metric
FB1: Ferrite_Bead_Small; C_1206_3216Metric_Pad1.33x1.80mm_HandSolder
J1: SJ2-35355A-SMT-TR; CUI_SJ2-35355A-SMT-TR
JP1, JP5, JP6: SolderJumper_2_Bridged; SolderJumper-2_P1.3mm_Bridged_RoundedPad1.0x1.5mm
JP2: 0R; R_0805_2012Metric_Pad1.20x1.40mm_HandSolder
JP3, JP4, JP7, JP9, JP10: SolderJumper_2_Open; SolderJumper-2_P1.3mm_Open_RoundedPad1.0x1.5mm
P1: Express_Card; generic_expresscard
R1: 24,3k; R_0805_2012Metric_Pad1.20x1.40mm_HandSolder
R2: 15k; R_0805_2012Metric_Pad1.20x1.40mm_HandSolder
R3, R30, R31: 1k; R_0805_2012Metric_Pad1.20x1.40mm_HandSolder
R4, R6, R21, R26: 20k; R_0805_2012Metric_Pad1.20x1.40mm_HandSolder
R5: 2R; R_0805_2012Metric_Pad1.20x1.40mm_HandSolder
R7, R8, R18, R27: 22R; R_0805_2012Metric_Pad1.20x1.40mm_HandSolder
R9: 1k5; R_0805_2012Metric_Pad1.20x1.40mm_HandSolder
R10, R12, R13, R14, R15, R22, R23: 100k; R_0805_2012Metric_Pad1.20x1.40mm_HandSolder
R11: 1M; R_0805_2012Metric_Pad1.20x1.40mm_HandSolder
R16, R29: 6k8; R_0805_2012Metric_Pad1.20x1.40mm_HandSolder
R17, R19, R24, R28: N/C; R_0805_2012Metric_Pad1.20x1.40mm_HandSolder
R20, R25: 10k; R_0805_2012Metric_Pad1.20x1.40mm_HandSolder
SW1, SW2: SW_DPDT_x2; AYZ0202AGRLC
SW3, SW4, SW5: SW_DPDT_x2; PTS526SM08SMTR2LFS
TP1: 3V3_prog; TestPoint_Pad_D2.5mm
TP2: SDA_prog; TestPoint_Pad_D2.5mm
TP3: SCL_prog; TestPoint_Pad_D2.5mm
TP4: SPDIF; TestPoint_Pad_D3.0mm
TP5: mic; TestPoint_Pad_D3.0mm
TP6: 3V3AUX; TestPoint_Pad_D3.0mm
TP7, TP8: GND; TestPoint_Pad_D3.0mm
U1: 24CW320T-I_ST; TSSOP-8_4.4x3mm_P0.65mm
U2: ADP7142ARDZ; SOIC-8-1EP_3.9x4.9mm_P1.27mm_EP2.29x3mm
U3: PCM2704CDBR; SOP65P780X200-28N
U4: LM4917; SOP65P640X120-14N
Y1: Crystal_GND24; Crystal_SMD_Abracon_ABM3C-4Pin_5.0x3.2mm

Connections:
+3V3: C1.1, C2.1, C16.2, C19.2, C24.2, JP2.2, JP3.1, JP4.2, JP5.1, JP6.1, R1.2, R2.1, R3.1, R22.2, R23.1, R30.1, R31.2, U2.1, U2.2, U3.10, U3.25, U3.26, U4.2, U4.9
/3V3_PC: C3.1, FB1.2, P1.14, P1.15
/D+: R8.1, R9.1, U3.9
/D-: R7.1, U3.8
/HPL: C13.1, J1.2, J1.5, R16.1, R21.2, U4.8
/HPR: C17.1, J1.3, R26.2, R29.1, U4.11
/SCL: R6.2, TP3.1, U1.6, U3.2
/SDA: R4.2, TP2.1, U1.5, U3.3
/SPDIF: TP4.1, U3.5
/amp_mute_l: JP10.2, R22.1, U4.12
/amp_mute_r: JP9.2, R23.2, U4.1
/dac_left: C11.2, C12.1, U3.14
/dac_right: C18.1, C20.2, U3.15
/dac_sus: R13.1, R14.1, R15.1, U3.27
GNDA: C1.2, C3.2, C5.2, C6.2, C7.2, C8.2, C9.2, C10.2, C14.1, C16.1, C19.1, C21.2, C22.2, C23.2, C24.1, D1.1, J1.4, JP1.1, P1.1, P1.17, P1.20, P1.23, P1.26, R2.2, R5.1, R10.1, R12.2, R18.2, R19.2, R24.2, R27.2, SW2.2, SW2.5, TP7.1, TP8.1, U1.4, U2.4, U2.9, U3.6, U3.11, U3.12, U3.17, U3.19, U4.4, U4.14, Y1.2, Y1.4
unnamed: C2.2, R3.2
unnamed: C4.1, C5.1, FB1.1, JP2.1, U2.5, U2.7, U2.8
unnamed: C4.2, R5.2
unnamed: C8.1, U3.18
unnamed: C11.1, R18.1
unnamed: C12.2, R17.1, R19.1, R20.1
unnamed: C13.2, R20.2, R21.1, SW1.2, U4.10
unnamed: C14.2, U4.6, U4.7
unnamed: C15.1, U4.3
unnamed: C15.2, U4.5
unnamed: C17.2, R25.2, R26.1, SW1.5, U4.13
unnamed: C18.2, R24.1, R25.1, R28.1
unnamed: C20.1, R27.1
unnamed: C21.1, R11.2, U3.1, Y1.1
unnamed: C22.1, R11.1, U3.28, Y1.3
unnamed: C23.1, U2.6
unnamed: D1.2, R30.2, R31.1
unnamed: J1.6, TP5.1
unnamed: JP1.2, P1.4
unnamed: JP3.2, R10.2, U3.4
unnamed: JP4.1, R4.1, R6.1, TP1.1, U1.8
unnamed: JP6.2, JP7.1, U3.21
unnamed: JP7.2, R12.1
unnamed: JP9.1, SW2.3
unnamed: JP10.1, SW2.6
unnamed: P1.2, R7.2
unnamed: P1.3, R8.2
unnamed: P1.12, TP6.1
unnamed: R1.1, U2.3
unnamed: R13.2, SW3.1
unnamed: R14.2, SW4.1
unnamed: R15.2, SW5.2
unnamed: R16.2, SW1.1
unnamed: R17.2, SW1.3
unnamed: R28.2, SW1.6
unnamed: R29.2, SW1.4
unnamed: SW3.2, U3.24
unnamed: SW4.2, U3.23
unnamed: SW5.1, U3.22
VDD: C6.1, C7.1, C9.1, C10.1, JP5.2, R9.2, U3.7, U3.13, U3.16, U3.20
